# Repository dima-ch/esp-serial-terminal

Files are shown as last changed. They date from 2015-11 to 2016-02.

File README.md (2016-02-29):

esp-serial-terminal
==========================
ESP8266 WiFi - RS232 мост. Дополнительная функция - управление реле. Применимо для замыкания контактов кнопки питания ПК.
Разработано для реализации удаленного терминала для домашнего сервера. Позволяет работать с системой до загрузки сетевых интерфейсов и возможности использования SSH/VNC. 
Например, управление grub, ввод пароля от зашифрованного корневого раздела, решение проблем отказа монтирования ФС, или просто ttyS консоль.

Прошивка форкнута от [ESP8266-transparent-bridge project](https://github.com/beckdac/ESP8266-transparent-bridge).
Использовалась ESP8266 KiCAD библиотека [techinc-kicad-lib](https://github.com/techinc/techinc-kicad-lib).

Собранная прошивка в [релизах] (https://github.com/dima-ch/esp-serial-terminal/releases).

#Аппаратная часть
На текущий момент аппаратная часть доступна для модуля ESP8266 ESP-03. Схема и печатная плата в формате KiCAD лежат в каталоге schematic. GPIO2 модуля подключен к светодиоду индикации.
GPIO14 подключен к реле. Выбран GPIO14 поскльку логический уровень на нем не прыгает при включение ESP8266.

#Индикация
* Светодиод моргает  во время работы
* Когда подключен клиент светодиод моргает медленнее

Подключение удобно производить клиентами telnet. 
ConnectBot для Android работает с настройками по умолчанию, утилита Linux telnet требует переменной окружения export TERM=VT100, параметра -8 и выполнения после подключения ^]mode character.

#Конфигурация
Следует убедиться, что в коде установлен #define CONFIG_DYNAMIC

Конфигурационные и управляющие AT команды
```
+++AT                                    # вывод в ответ OK
+++AT PWBTN <duration: SHORT, LONG, HARDRESET>
										 # Управление контактами реле: SHORT - замыкание на 0.5с, LONG - на 4с, HARDRESET - 4c, пауза в 1c, затем 0.5с
+++AT MODE                               # вывод текущего режима
+++AT MODE <mode: 1= STA, 2= AP, 3=both> # установка режима
+++AT STA                                # вывести текущий ssid и пароль подключения к точке доступа
+++AT STA <ssid> <password>              # установить ssid и пароль к точке доступа
+++AT AP                                 # вывести текущие настройки точки доступа
+++AT AP <ssid>                          # установить режим открытой точки доступа с указанным ssid
+++AT AP <ssid> <pw> [<authmode> [hide-ssid [<ch>]]]]
										 # установить параметры точки доступа, authmode:1= WEP,2= WPA,3= WPA2,4= WPA+WPA2, 
										 # hide-ssid:1-hide, 0-show(not hide), channel: 1..13
+++AT BAUD                               # вывести текущие настройки UART
+++AT BAUD <baud> [data [parity [stop]]] # установить битрейт и опционально data bits = 5/6/7/8 , parity = N/E/O, stop bits = 1/1.5/2
+++AT PORT                               # вывести текущей TCP порт
+++AT PORT <port>                        # установить TCP порт (перезагрузка)
+++AT FLASH                              # вывод настроек сохранения
+++AT FLASH <1|0>                        # 1: изменение настроек UART (++AT BAUD ...) сохраняется (по умолчанию), 0: изменения не сохраняются
+++AT RESET                              # программная перезагрузка
```
В случае успеха все команды возвращают "OK" или соответствующий вывод. На заметку, пароль и ssid не могут содержать пробелов.

Пример конфигурирования. telnet используется без ключей и настроек в отличие от режима работы. Если нет ответа на команду +++AT при ручном вводе, рекомендую вставлять команду в терминал из буфера обмена.
```
user@host:~$ telnet 192.168.1.197
Trying 192.168.1.197...
Connected to 192.168.1.197.
Escape character is '^]'.
+++AT MODE
MODE=3
OK
+++AT AP
SSID=ESP_9E2EA6 PASSWORD= AUTHMODE=0 IS_HIDDEH_SSID=0 CHANNEL=3
OK
+++AT AP newSSID password
OK
+++AT AP
SSID=newSSID PASSWORD=password AUTHMODE=2 IS_HIDDEH_SSID=0 CHANNEL=3
OK
+++AT AP ESP_9E2EA6
OK
+++AT AP
SSID=ESP_9E2EA6 PASSWORD= AUTHMODE=0 CHANNEL=3
OK
^]c

telnet> c
Connection closed.
```

Прошивка:
```
esptool.py --port /dev/ttyXXX write_flash 0x00000 0x00000.bin 0x40000 0x40000.bin
...
или с использованием ESP8266Flasher.exe из https://github.com/nodemcu/nodemcu-flasher с
0x00000.bin по адресу 0x00000
0x40000.bin по адресу 0x40000

Дополнительно см. [ESP8266-transparent-bridge project](https://github.com/beckdac/ESP8266-transparent-bridge)

#TODO
* ошибка на печатной плате и схеме, перепутаны пины DB9
* уменьшение клиентов до 2 и увеличение буфера отправки

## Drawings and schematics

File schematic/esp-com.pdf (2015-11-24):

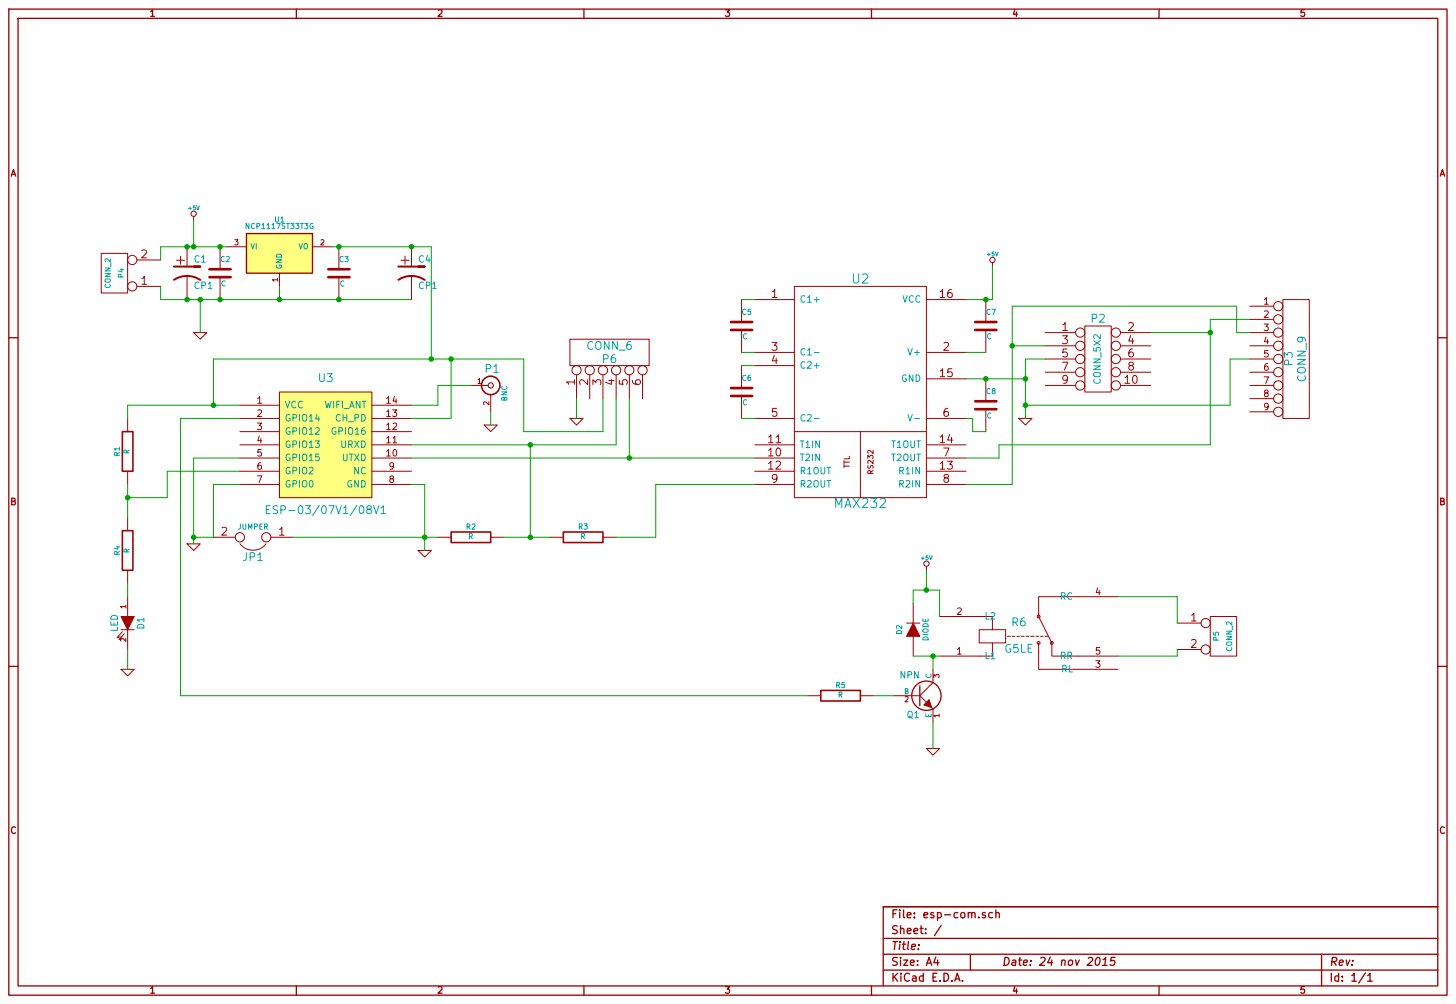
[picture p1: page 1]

Id: 1/1 Title: File: esp-com.sch

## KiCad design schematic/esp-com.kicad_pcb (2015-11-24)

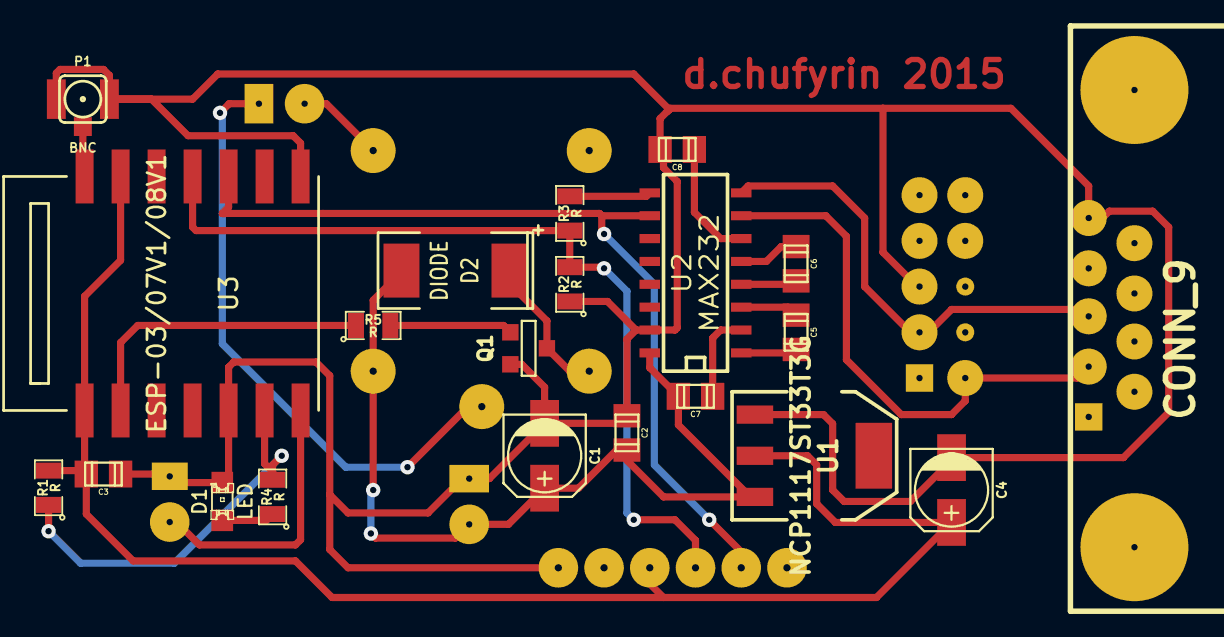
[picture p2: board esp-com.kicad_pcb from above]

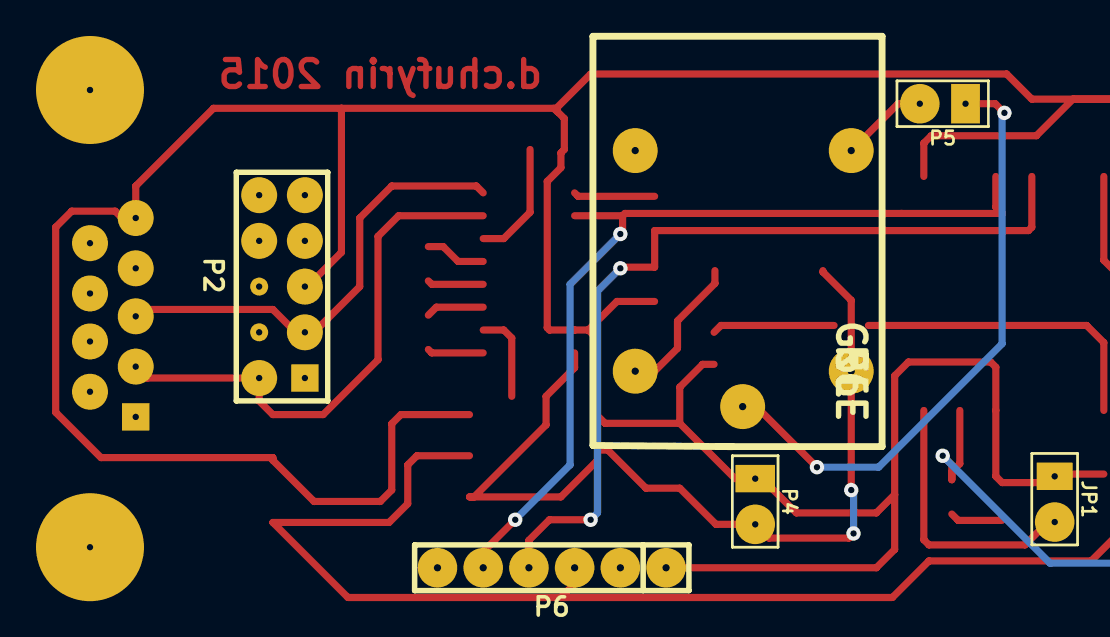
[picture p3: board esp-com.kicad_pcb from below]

Board: 2 copper layers, 27 parts (6 on the bottom side), 22 nets.

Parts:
C1: CP1; c_elec_4x5.8
C2, C3, C5, C6, C7, C8: C; c_0805
C4: CP1; c_elec_4x5.7
D1: LED; LED-0805
D2: DIODE; SM2512
JP1: JUMPER; PIN_ARRAY_2X1
P1: BNC; coaxial_u.fl-r-smt-1
P2: CONN_5X2; PIN_ARRAY_5x2
P3: CONN_9; DB9MC
P4, P5: CONN_2; PIN_ARRAY_2X1
P6: CONN_6; PIN_ARRAY-6X1
Q1: NPN; SOT23EBC
R1, R2, R3, R4, R5: R; SM0805
R6: G5LE
U1: NCP1117ST33T3G; SOT223
U2: MAX232; SO16E
U3: ESP-03/07V1/08V1; ESP-03

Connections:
+5V: C1.1, C2.1, C7.1, D2.2, P4.2, R6.2, U1.3, U2.16
GND: C1.2, C2.2, C3.2, C4.2, C8.1, D1.2, JP1.1, JP1.2, P1.2, P2.5, P3.5, P4.1, P6.1, Q1.1, R2.1, U1.1, U2.15, U3.5, U3.7, U3.8
unnamed: P2.2, P3.2, U2.7
unnamed: P2.3, P3.3, U2.8
unnamed: D2.1, Q1.3, R6.1
unnamed: C7.2, U2.2
unnamed: C8.2, U2.6
unnamed: C5.2, U2.3
unnamed: C5.1, U2.1
unnamed: C6.1, U2.4
unnamed: C6.2, U2.5
unnamed: R3.2, U2.9
unnamed: P6.4, R2.2, R3.1, U3.11
unnamed: P1.1, U3.14
unnamed: R5.1, U3.2
unnamed: D1.1, R4.1
unnamed: Q1.2, R5.2
unnamed: P5.2, R6.5
unnamed: P5.1, R6.4
unnamed: P6.5, U2.10, U3.10
unnamed: R1.1, R4.2, U3.6
unnamed: C3.1, C4.1, P6.3, R1.2, U1.2, U3.1, U3.13

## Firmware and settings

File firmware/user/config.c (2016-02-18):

#ifndef CONFIG_PARSE_TEST_UNIT

// this is the normal build target ESP include set
//#include "espmissingincludes.h"
#include "c_types.h"
#include "user_interface.h"
#include "espconn.h"
#include "mem.h"
#include "osapi.h"
#include "driver/uart.h"

#include "flash_param.h"
#include "server.h"

#else

// test unit target for config_parse
// gcc -g -o config_test config.c -D CONFIG_PARSE_TEST_UNIT
// ./config_test < config_test.cmd
#include <stdio.h>
#include <stdlib.h>
#include <string.h>
#include <stdint.h>

struct espconn {
	int dummy;
};

struct station_config {
	uint8_t ssid[32];
	uint8_t password[64];
	uint8_t bssid_set;
	uint8_t bssid[6];
};

struct softap_config {
	uint8_t ssid[32];
	uint8_t password[64];
	uint8_t ssid_len;
	uint8_t channel;
	uint8_t authmode;
	uint8_t ssid_hidden;
	uint8_t max_connection;
};

// #define os_sprintf	sprintf
// #define os_malloc	malloc
// #define os_strncpy	strncpy
// #define os_strncmp	strncmp
// #define os_free		free
// #define os_bzero	bzero
// #define os_memcpy	memcpy
// #define os_memset	memset

#define espconn_sent(conn, buf, len)	printf(buf)

#define AUTH_OPEN 0
#define AUTH_WPA_PSK 2
#define AUTH_WPA2_PSK 3

#define wifi_get_opmode() (printf("wifi_get_opmode()\n") ? 2 : 2)
#define wifi_set_opmode(mode) printf("wifi_set_opmode(%d)\n", mode)
#define wifi_station_disconnect() printf("wifi_station_disconnect()\n")
#define wifi_station_get_config(conf) { strncpy((conf)->ssid, "dummystassid", 32); strncpy((conf)->password, "dummystapassword", 64); }
#define wifi_station_set_config(conf) printf("wifi_station_set_config(%s, %s)\n", (conf)->ssid, (conf)->password)
#define wifi_station_connect() printf("wifi_station_connect()\n");
#define wifi_get_macaddr(if, result) printf("wifi_get_mac_addr(SOFTAP_IF, macaddr)\n")
#define wifi_softap_get_config(conf) { strncpy((conf)->ssid, "dummyapssid", 32); strncpy((conf)->password, "dummyappassword", 64); (conf)->authmode=AUTH_WPA_PSK; (conf)->channel=3; }
#define wifi_softap_set_config(conf) printf("wifi_softap_set_config(%s, %s, %d, %d)\n", (conf)->ssid, (conf)->password, (conf)->authmode, (conf)->channel)
#define system_restart() printf("system_restart()\n");
#define ETS_UART_INTR_DISABLE()	printf("ETS_UART_INTR_DISABLE()\n");
#define ETS_UART_INTR_ENABLE()	printf("ETS_UART_INTR_ENABLE()\n");

#endif

#include "config.h"

void config_gpio(void) {
	// Initialize the GPIO subsystem.
	gpio_init();
	//Set GPIO2 to output mode
	PIN_FUNC_SELECT(PERIPHS_IO_MUX_GPIO2_U, FUNC_GPIO2);
	//Set GPIO2 high
	gpio_output_set(BIT2, 0, BIT2, 0);


	//Set GPIO14 to output mode
	PIN_FUNC_SELECT(PERIPHS_IO_MUX_MTMS_U, FUNC_GPIO14);
	//Set GPIO2 high
	GPIO_OUTPUT_SET(PWBTN_PIN, 0);
}

#ifdef CONFIG_STATIC

void config_execute(void) {
	uint8_t mode;
	struct station_config sta_conf;
	struct softap_config ap_conf;
	uint8_t macaddr[6] = { 0, 0, 0, 0, 0, 0 };

	// make sure the device is in AP and STA combined mode
	mode = wifi_get_opmode();
	if (mode != STATIONAP_MODE) {
		wifi_set_opmode(STATIONAP_MODE);
		os_delay_us(10000);
		system_restart();
	}

	// connect to our station
	os_bzero(&sta_conf, sizeof(struct station_config));
	wifi_station_get_config(&sta_conf);
	os_strncpy(sta_conf.ssid, STA_SSID, sizeof(sta_conf.ssid));
	os_strncpy(sta_conf.password, STA_PASSWORD, sizeof(sta_conf.password));
	wifi_station_disconnect();
	ETS_UART_INTR_DISABLE();
	wifi_station_set_config(&sta_conf);
	ETS_UART_INTR_ENABLE();
	wifi_station_connect();

	// setup the soft AP
	os_bzero(&ap_conf, sizeof(struct softap_config));
	wifi_softap_get_config(&ap_conf);
	wifi_get_macaddr(SOFTAP_IF, macaddr);
	os_strncpy(ap_conf.ssid, AP_SSID, sizeof(ap_conf.ssid));
	ap_conf.ssid_len = strlen(AP_SSID);
	os_strncpy(ap_conf.password, AP_PASSWORD, sizeof(ap_conf.password));
	//os_snprintf(&ap_conf.password[strlen(AP_PASSWORD)], sizeof(ap_conf.password) - strlen(AP_PASSWORD), "_%02X%02X%02X", macaddr[3], macaddr[4], macaddr[5]);
	os_sprintf(ap_conf.password[strlen(AP_PASSWORD)], "_%02X%02X%02X", macaddr[3], macaddr[4], macaddr[5]);
	ap_conf.authmode = AUTH_WPA_PSK;
	ap_conf.channel = 6;
	ETS_UART_INTR_DISABLE();
	wifi_softap_set_config(&ap_conf);
	ETS_UART_INTR_ENABLE();
}

#endif

#ifdef CONFIG_DYNAMIC

#define MSG_OK "OK\r\n"
#define MSG_ERROR "ERROR\r\n"
#define MSG_INVALID_CMD "UNKNOWN COMMAND\r\n"

#define MAX_ARGS 12
#define MSG_BUF_LEN 128

#ifdef CONFIG_PARSE_TEST_UNIT
#endif

bool doflash = true;

char *my_strdup(char *str) {
	size_t len;
	char *copy;

	len = strlen(str) + 1;
	if (!(copy = (char*)os_malloc((u_int)len)))
		return (NULL);
	os_memcpy(copy, str, len);
	return (copy);
}

char **config_parse_args(char *buf, uint8_t *argc) {
	const char delim[] = " \t";
	char *save, *tok;
	char **argv = (char **)os_malloc(sizeof(char *) * MAX_ARGS);	// note fixed length
	os_memset(argv, 0, sizeof(char *) * MAX_ARGS);

	*argc = 0;
	for (; *buf == ' ' || *buf == '\t'; ++buf); // absorb leading spaces
	for (tok = strtok_r(buf, delim, &save); tok; tok = strtok_r(NULL, delim, &save)) {
		argv[*argc] = my_strdup(tok);
		(*argc)++;
		if (*argc == MAX_ARGS) {
			break;
		}
	}
	return argv;
}

void config_parse_args_free(uint8_t argc, char *argv[]) {
	uint8_t i;
	for (i = 0; i <= argc; ++i) {
		if (argv[i])
			os_free(argv[i]);
	}
	os_free(argv);
}

void config_cmd_reset(serverConnData *conn, uint8_t argc, char *argv[]) {
	espbuffsentstring(conn, MSG_OK);
	system_restart();
}

volatile char short_press_flag;
volatile char long_press_flag;
volatile char hardrest_press_flag;
void config_cmd_power_button(serverConnData *conn, uint8_t argc, char *argv[]) {
	if (argc == 0)
	{
		espbuffsentprintf(conn, "Args: SHORT - 0.5s press, LONG - 5s press, HARDRESET - 5s press, 2s pause, 0.5s press\r\n");
	}
	else
	{
		if(short_press_flag || long_press_flag || hardrest_press_flag)
		{
			espbuffsentstring(conn, MSG_ERROR); // power button command currently execute
		}
		else if (!strcmp(argv[1], "SHORT")) {
			short_press_flag = 1;
			espbuffsentstring(conn, "SHORT PRESS\r\n");
		}
		else if (!strcmp(argv[1], "LONG")) {
			long_press_flag = 1;
			espbuffsentstring(conn, "LONG PRESS\r\n");
		}
		else if (!strcmp(argv[1], "HARDRESET"))  {
			hardrest_press_flag = 1;
			espbuffsentstring(conn, "HARDRESET\r\n");
		}
		else
		{
			espbuffsentstring(conn, MSG_ERROR);
		}
	}
}

void config_cmd_baud(serverConnData *conn, uint8_t argc, char *argv[]) {
	flash_param_t *flash_param = flash_param_get();
	UartBitsNum4Char data_bits = GETUART_DATABITS(flash_param->uartconf0);
	UartParityMode parity = GETUART_PARITYMODE(flash_param->uartconf0);
	UartStopBitsNum stop_bits = GETUART_STOPBITS(flash_param->uartconf0);
	const char *stopbits[4] = { "?", "1", "1.5", "2" };
	const char *paritymodes[4] = { "E", "O", "N", "?" };
	if (argc == 0)
		espbuffsentprintf(conn, "BAUD=%d %d %s %s\r\n"MSG_OK, flash_param->baud,data_bits + 5, paritymodes[parity], stopbits[stop_bits]);
	else {
		uint32_t baud = atoi(argv[1]);
		if ((baud > (UART_CLK_FREQ / 16)) || baud == 0) {
			espbuffsentstring(conn, MSG_ERROR);
			return;
		}
		if (argc > 1) {
			data_bits = atoi(argv[2]);
			if ((data_bits < 5) || (data_bits > 8)) {
				espbuffsentstring(conn, MSG_ERROR);
				return;
			}
			data_bits -= 5;
		}
		if (argc > 2) {
			if (strcmp(argv[3], "N") == 0)
				parity = NONE_BITS;
			else if (strcmp(argv[3], "O") == 0)
				parity = ODD_BITS;
			else if (strcmp(argv[3], "E") == 0)
				parity = EVEN_BITS;
			else {
				espbuffsentstring(conn, MSG_ERROR);
				return;
			}
		}
		if (argc > 3) {
			if (strcmp(argv[4], "1")==0)
				stop_bits = ONE_STOP_BIT;
			else if (strcmp(argv[4], "2")==0)
				stop_bits = TWO_STOP_BIT;
			else if (strcmp(argv[4], "1.5") == 0)
				stop_bits = ONE_HALF_STOP_BIT;
			else {
				espbuffsentstring(conn, MSG_ERROR);
				return;
			}
		}
		// pump and dump fifo
		while (TRUE) {
			uint32_t fifo_cnt = READ_PERI_REG(UART_STATUS(0)) & (UART_TXFIFO_CNT << UART_TXFIFO_CNT_S);
			if ((fifo_cnt >> UART_TXFIFO_CNT_S & UART_TXFIFO_CNT) == 0) {
				break;
			}
		}
		os_delay_us(10000);
		uart_div_modify(UART0, UART_CLK_FREQ / baud);
		flash_param->baud = baud;
		flash_param->uartconf0 = CALC_UARTMODE(data_bits, parity, stop_bits);
		WRITE_PERI_REG(UART_CONF0(UART0), flash_param->uartconf0);
		if (doflash) {
			if (flash_param_set())
				espbuffsentstring(conn, MSG_OK);
			else
				espbuffsentstring(conn, MSG_ERROR);
		}
		else
			espbuffsentstring(conn, MSG_OK);

	}
}

void config_cmd_flash(serverConnData *conn, uint8_t argc, char *argv[]) {
	bool err = false;
	if (argc == 0)
		espbuffsentprintf(conn, "FLASH=%d\r\n", doflash);
	else if (argc != 1)
		err=true;
	else {
		if (strcmp(argv[1], "1") == 0)
			doflash = true;
		else if (strcmp(argv[1], "0") == 0)
			doflash = false;
		else
			err=true;
	}
	if (err)
		espbuffsentstring(conn, MSG_ERROR);
	else
		espbuffsentstring(conn, MSG_OK);


}

void config_cmd_port(serverConnData *conn, uint8_t argc, char *argv[]) {
	flash_param_t *flash_param = flash_param_get();

	if (argc == 0)
		espbuffsentprintf(conn, "PORT=%d\r\n"MSG_OK, flash_param->port);
	else if (argc != 1)
		espbuffsentstring(conn, MSG_ERROR);
	else {
		uint32_t port = atoi(argv[1]);
		if ((port == 0)||(port>65535)) {
			espbuffsentstring(conn, MSG_ERROR);
		} else {
			if (port != flash_param->port) {
				flash_param->port = port;
				if (flash_param_set())
					espbuffsentstring(conn, MSG_OK);
				else
					espbuffsentstring(conn, MSG_ERROR);
				os_delay_us(10000);
				system_restart();
			} else {
				espbuffsentstring(conn, MSG_OK);
			}
		}
	}
	// debug
	{
		espbuffsentprintf(conn, "flash param:\n\tmagic\t%d\n\tversion\t%d\n\tbaud\t%d\n\tport\t%d\n",
			flash_param->magic, flash_param->version, flash_param->baud, flash_param->port);
	}
}

void config_cmd_mode(serverConnData *conn, uint8_t argc, char *argv[]) {
	uint8_t mode;

	if (argc == 0) {
		espbuffsentprintf(conn, "MODE=%d\r\n"MSG_OK, wifi_get_opmode());
	} else if (argc != 1) {
		espbuffsentstring(conn, MSG_ERROR);
	} else {
		mode = atoi(argv[1]);
		if (mode >= 1 && mode <= 3) {
			if (wifi_get_opmode() != mode) {
				ETS_UART_INTR_DISABLE();
				wifi_set_opmode(mode);
				ETS_UART_INTR_ENABLE();
				espbuffsentstring(conn, MSG_OK);
				os_delay_us(10000);
				system_restart();
			} else {
				espbuffsentstring(conn, MSG_OK);
			}
		} else {
			espbuffsentstring(conn, MSG_ERROR);
		}
	}
}

// spaces are not supported in the ssid or password
void config_cmd_sta(serverConnData *conn, uint8_t argc, char *argv[]) {
	char *ssid = argv[1], *password = argv[2];
	struct station_config sta_conf;

	os_bzero(&sta_conf, sizeof(struct station_config));
	wifi_station_get_config(&sta_conf);

	if (argc == 0)
		espbuffsentprintf(conn, "SSID=%s PASSWORD=%s\r\n"MSG_OK, sta_conf.ssid, sta_conf.password);
	 else if (argc != 2)
		espbuffsentstring(conn, MSG_ERROR);
	else {
		os_strncpy(sta_conf.ssid, ssid, sizeof(sta_conf.ssid));
		os_strncpy(sta_conf.password, password, sizeof(sta_conf.password));
		espbuffsentstring(conn, MSG_OK);
		wifi_station_disconnect();
		ETS_UART_INTR_DISABLE();
		wifi_station_set_config(&sta_conf);
		ETS_UART_INTR_ENABLE();
		wifi_station_connect();
	}
}

// spaces are not supported in the ssid or password
void config_cmd_ap(serverConnData *conn, uint8_t argc, char *argv[]) {
	char *ssid = argv[1], *password = argv[2];
	struct softap_config ap_conf;
#define MAXAUTHMODES 5
	os_bzero(&ap_conf, sizeof(struct softap_config));
	wifi_softap_get_config(&ap_conf);
	if (argc == 0)
		espbuffsentprintf(conn, "SSID=%s PASSWORD=%s AUTHMODE=%d IS_HIDDEH_SSID=%d CHANNEL=%d\r\n"MSG_OK, ap_conf.ssid, ap_conf.password, ap_conf.authmode, ap_conf.ssid_hidden, ap_conf.channel);
	else if (argc > 5)
		espbuffsentstring(conn, MSG_ERROR);
	else { //argc > 0
		os_strncpy(ap_conf.ssid, ssid, sizeof(ap_conf.ssid));
		ap_conf.ssid_len = strlen(ssid); //without set ssid_len, no connection to AP is possible
		if (argc == 1) { //  no password
			os_bzero(ap_conf.password, sizeof(ap_conf.password));
			ap_conf.authmode = AUTH_OPEN;
		} else { // with password
			os_strncpy(ap_conf.password, password, sizeof(ap_conf.password));
			if (argc > 2) { // authmode
				int amode = atoi(argv[3]);
				if ((amode < 1) || (amode>4)) {
					espbuffsentstring(conn, MSG_ERROR);
					return;
				}
				ap_conf.authmode = amode;
			}
			if (argc > 3) { //ssid_hidden
				int ssid_hidden = atoi(argv[4]);
				if ((ssid_hidden > 1) || (ssid_hidden < 0)){
					espbuffsentstring(conn, MSG_ERROR);
					return;
				}
				ap_conf.ssid_hidden = ssid_hidden;
				if (argc > 4) { //channel
					int chan = atoi(argv[5]);
					if ((chan < 1) || (chan>13)){
						espbuffsentstring(conn, MSG_ERROR);
						return;
					}
					ap_conf.channel = chan;
				}
			}
		}
		espbuffsentstring(conn, MSG_OK);
		ETS_UART_INTR_DISABLE();
		wifi_softap_set_config(&ap_conf);
		ETS_UART_INTR_ENABLE();
	}
}

const config_commands_t config_commands[] = {
		{ "RESET", &config_cmd_reset },
		{ "BAUD", &config_cmd_baud },
		{ "PORT", &config_cmd_port },
		{ "MODE", &config_cmd_mode },
		{ "STA", &config_cmd_sta },
		{ "AP", &config_cmd_ap },
		{ "FLASH", &config_cmd_flash },
		{ "PWBTN", &config_cmd_power_button },
		{ NULL, NULL }
	};

void config_parse(serverConnData *conn, char *buf, int len) {
	char *lbuf = (char *)os_malloc(len + 1), **argv;
	uint8_t i, argc;
	// we need a '\0' end of the string
	os_memcpy(lbuf, buf, len);
	lbuf[len] = '\0';

	// command echo
	//espbuffsent(conn, lbuf, len);

	// remove any CR / LF
	for (i = 0; i < len; ++i)
		if (lbuf[i] == '\n' || lbuf[i] == '\r')
			lbuf[i] = '\0';

	// verify the command prefix
	if (os_strncmp(lbuf, "+++AT", 5) != 0) {
		return;
	}
	// parse out buffer into arguments
	argv = config_parse_args(&lbuf[5], &argc);
#if 0
// debugging
	{
		uint8_t i;
		for (i = 0; i < argc; ++i) {
			espbuffsentprintf(conn, "argument %d: '%s'\r\n", i, argv[i]);
		}
	}
// end debugging
#endif
	if (argc == 0) {
		espbuffsentstring(conn, MSG_OK);
	} else {
		argc--;	// to mimic C main() argc argv
		for (i = 0; config_commands[i].command; ++i) {
			if (os_strncmp(argv[0], config_commands[i].command, strlen(argv[0])) == 0) {
				config_commands[i].function(conn, argc, argv);
				break;
			}
		}
		if (!config_commands[i].command)
			espbuffsentstring(conn, MSG_INVALID_CMD);
	}
	config_parse_args_free(argc, argv);
	os_free(lbuf);
}

#ifdef CONFIG_PARSE_TEST_UNIT
const int max_line = 255;
int main(int argc, char *argv[]) {
	char line[max_line];

	// read lines and feed them to config_parse
	while (fgets(line, max_line, stdin) != NULL) {
		uint8_t len = strlen(line);
		config_parse(NULL, line, len);
	}
}
#endif

#endif

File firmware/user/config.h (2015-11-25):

#ifndef __CONFIG_H__
#define __CONFIG_H__

//#define CONFIG_STATIC
#ifdef CONFIG_STATIC

#define STA_SSID	"ssid2join"
#define STA_PASSWORD	"password"
#define AP_SSID		"myssid"
#define AP_PASSWORD	"password"
// over ride in this file
#include "config_wifi.h"

void config_execute(void);

#endif

#define CONFIG_DYNAMIC
#ifdef CONFIG_DYNAMIC

typedef struct config_commands {
	char *command;
	void(*function)(serverConnData *conn, uint8_t argc, char *argv[]);
} config_commands_t;


void config_parse(serverConnData *conn, char *buf, int len);

#endif


#include <gpio.h>

void config_gpio(void);

extern volatile char short_press_flag;
extern volatile char long_press_flag;
extern volatile char hardrest_press_flag;

#define TIMER_DURATION_MS 500

#define PWBTN_SHORT_PRESS_MS 500
#define PWBTN_LONG_PRESS_MS 6000
#define PWBTN_HARDRESET_PAUSE_MS 2000

#define LED_PIN 2
#define PWBTN_PIN 14

#endif /* __CONFIG_H__ */

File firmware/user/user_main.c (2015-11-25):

/*
 * File	: user_main.c
 * This file is part of Espressif's AT+ command set program.
 * Copyright (C) 2013 - 2016, Espressif Systems
 *
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
 * You should have received a copy of the GNU General Public License along
 * with this program.	If not, see <http://www.gnu.org/licenses/>.
 */
#include "ets_sys.h"
#include "os_type.h"
#include "osapi.h"
#include "driver/uart.h"
#include "task.h"

#include "server.h"
#include "config.h"
#include "flash_param.h"

os_event_t		recvTaskQueue[recvTaskQueueLen];
extern  serverConnData connData[MAX_CONN];

#define MAX_UARTBUFFER (MAX_TXBUFFER/4)
static uint8 uartbuffer[MAX_UARTBUFFER];
static volatile os_timer_t  main_timer;

void led_rutine(void){
	static char counter = 0;
	char dv = 2;
	if(connected_client_flag){
		dv = 5;
	}
	if(counter%dv){
		GPIO_OUTPUT_SET(LED_PIN, 0);
	} else {
		GPIO_OUTPUT_SET(LED_PIN, 1);
	}
	counter++;
}

#define PWBTN_SHORT_PRESS_TICKS PWBTN_SHORT_PRESS_MS / TIMER_DURATION_MS
#define PWBTN_LONG_PRESS_TICKS PWBTN_LONG_PRESS_MS / TIMER_DURATION_MS
#define PWBTN_HARDRESET_PAUSE_TICKS PWBTN_HARDRESET_PAUSE_MS / TIMER_DURATION_MS

void gpio_rutine(void){
	static int i = 0;
	if (short_press_flag) {
		if (i++ == 0) {
			GPIO_OUTPUT_SET(PWBTN_PIN, 1);
		} else if (i > PWBTN_SHORT_PRESS_TICKS) {
			GPIO_OUTPUT_SET(PWBTN_PIN, 0);
			short_press_flag = 0;
			i = 0;
		}
	} else if (long_press_flag) {
		if (i++ == 0) {
			GPIO_OUTPUT_SET(PWBTN_PIN, 1);
		} else if (i > PWBTN_LONG_PRESS_TICKS) {
			GPIO_OUTPUT_SET(PWBTN_PIN, 0);
			long_press_flag = 0;
			i = 0;
		}
	} else if (hardrest_press_flag) {
		if (i++ == 0) {
			GPIO_OUTPUT_SET(PWBTN_PIN, 1);
		} else if (i == PWBTN_LONG_PRESS_TICKS) {
			GPIO_OUTPUT_SET(PWBTN_PIN, 0);
		} else if(i == PWBTN_LONG_PRESS_TICKS + PWBTN_HARDRESET_PAUSE_TICKS){
			GPIO_OUTPUT_SET(PWBTN_PIN, 1);
		} else if(i > PWBTN_LONG_PRESS_TICKS + PWBTN_HARDRESET_PAUSE_TICKS + PWBTN_SHORT_PRESS_TICKS){
			GPIO_OUTPUT_SET(PWBTN_PIN, 0);
			hardrest_press_flag = 0;
			i = 0;
		}
	}
}

void main_timer_callback(void *arg){
	led_rutine();
	gpio_rutine();
}

static void ICACHE_FLASH_ATTR recvTask(os_event_t *events)
{
	uint8_t i;	 
	while (READ_PERI_REG(UART_STATUS(UART0)) & (UART_RXFIFO_CNT << UART_RXFIFO_CNT_S))
	{
		WRITE_PERI_REG(0X60000914, 0x73); //WTD
		uint16 length = 0;
		while ((READ_PERI_REG(UART_STATUS(UART0)) & (UART_RXFIFO_CNT << UART_RXFIFO_CNT_S)) && (length<MAX_UARTBUFFER))
			uartbuffer[length++] = READ_PERI_REG(UART_FIFO(UART0)) & 0xFF;
		for (i = 0; i < MAX_CONN; ++i)
			if (connData[i].conn) 
				espbuffsent(&connData[i], uartbuffer, length);		
	}

	if(UART_RXFIFO_FULL_INT_ST == (READ_PERI_REG(UART_INT_ST(UART0)) & UART_RXFIFO_FULL_INT_ST))
	{
		WRITE_PERI_REG(UART_INT_CLR(UART0), UART_RXFIFO_FULL_INT_CLR);
	}
	else if(UART_RXFIFO_TOUT_INT_ST == (READ_PERI_REG(UART_INT_ST(UART0)) & UART_RXFIFO_TOUT_INT_ST))
	{
		WRITE_PERI_REG(UART_INT_CLR(UART0), UART_RXFIFO_TOUT_INT_CLR);
	}
	ETS_UART_INTR_ENABLE();
}


// UartDev is defined and initialized in rom code.
extern UartDevice    UartDev;

void ICACHE_FLASH_ATTR user_init(void)
{
	uint8_t i;
	//wifi_set_opmode(3); //STA+AP

	#ifdef CONFIG_DYNAMIC
		flash_param_t *flash_param;
		flash_param_init();
		flash_param = flash_param_get();
		UartDev.data_bits = GETUART_DATABITS(flash_param->uartconf0);
		UartDev.parity = GETUART_PARITYMODE(flash_param->uartconf0);
		UartDev.stop_bits = GETUART_STOPBITS(flash_param->uartconf0);
		uart_init(flash_param->baud, BIT_RATE_115200);
	#else
		UartDev.data_bits = EIGHT_BITS;
		UartDev.parity = NONE_BITS;
		UartDev.stop_bits = ONE_STOP_BIT;
		uart_init(BIT_RATE_115200, BIT_RATE_115200);
	#endif
	os_printf("size flash_param_t %d\n", sizeof(flash_param_t));


	#ifdef CONFIG_STATIC
		// refresh wifi config
		config_execute();
	#endif

	#ifdef CONFIG_DYNAMIC
		serverInit(flash_param->port);
	#else
		serverInit(23);
	#endif

	config_gpio();

    os_timer_disarm(&main_timer);
	os_timer_setfn(&main_timer, (os_timer_func_t *)main_timer_callback, NULL);
	os_timer_arm(&main_timer, TIMER_DURATION_MS, 1);

	system_os_task(recvTask, recvTaskPrio, recvTaskQueue, recvTaskQueueLen);
}

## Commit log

2015-11-24 Add power button cmd
2015-11-25 Power button control, led GPIO02 blink
2015-11-25 Led indicate connected telnet client
2016-02-25 schematic values
    [esp-com.sch]

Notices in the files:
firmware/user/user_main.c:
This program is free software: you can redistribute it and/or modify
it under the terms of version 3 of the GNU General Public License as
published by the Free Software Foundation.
